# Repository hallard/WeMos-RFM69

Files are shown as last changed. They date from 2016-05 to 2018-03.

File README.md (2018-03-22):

ESP8266 WeMos Shield for HopeRF RFM69 and RFM12 Modules
=======================================================

This shield is used to hold HopeRF RF [module][4] Software with WeMos ESP8266 boards it has just few minimal features. 
- I2C Pullups placement
- Classic I2C 128x64 OLED connector
- Placement for RFM12B/RFM69CW/RFM69W/RFM69HW RF module
- Placement for choosing single Wire, SMA or u-FL Antenna type
- 2 x WS2812B Type LED for visual indication
- Atmel ATSHA204 for crypto
- Custom switch on GPIO2

You can find more information on WeMos on their [site][1], it's really well documented.
I now use WeMos boards instead of NodeMCU's one because they're just smaller, features remains the same, but I also suspect WeMos regulator far better quality than the one used on NodeMCU that are just fake of originals AMS117 3V3.

Boards heve been tested with RFM69HW and are working fine, no problem so far, just a silk error on V1.0, RFM module indication is reversed.
This mean that RFM69W/RFM69HW is for RFM12B/RFM69CW and vice-versa, please check with module pinout before soldering.
**This have been corrected on V1.0a+ release**

**I didn't tested with RFM12/RFM69CW module.** If someone tested and have it working (or not), please let me know.

Detailed Description
====================

Look at the schematics for more informations.

### Schematic  
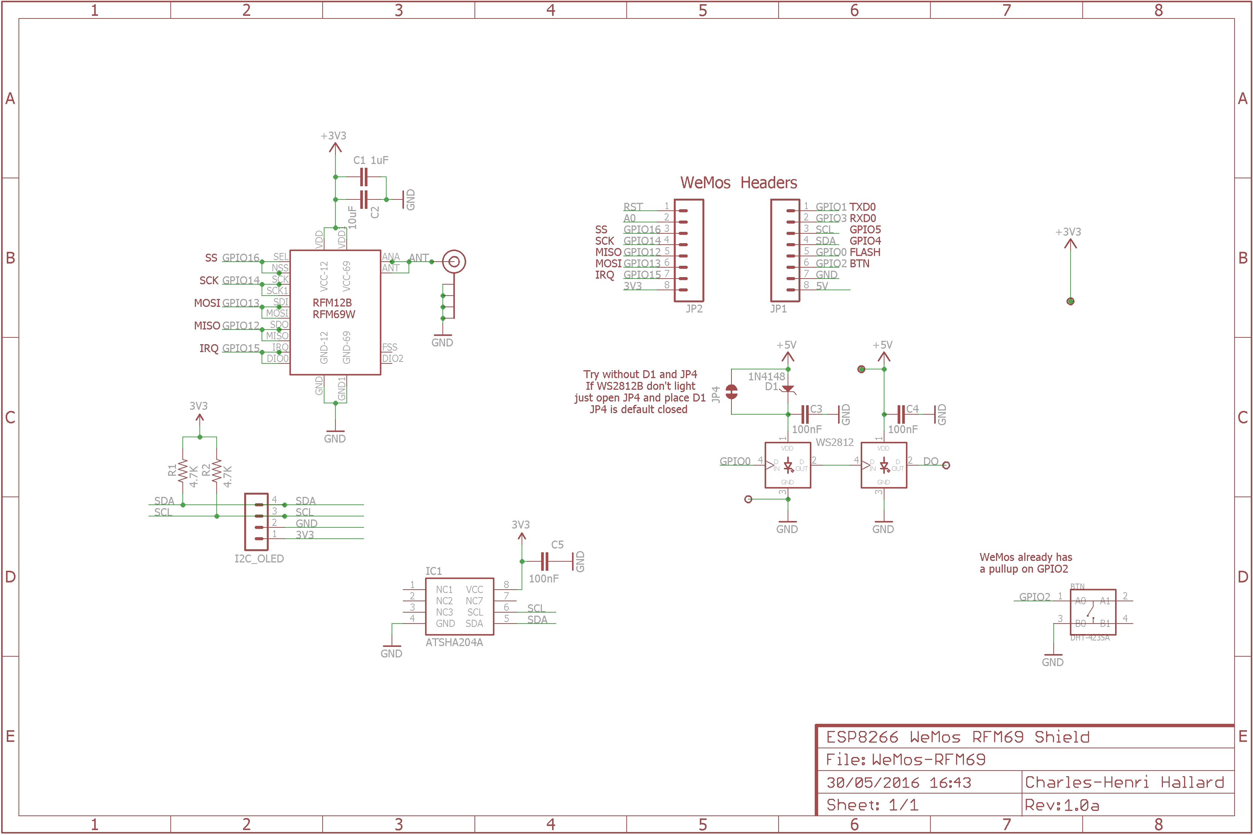
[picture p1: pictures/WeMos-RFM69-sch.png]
schematic
  

Diode D1 (1N4148) is for level voltage of WS2812B. Decreasing 1st led to VCC to 4.3V (see this [post][5]) but It should works out of the box (so without D1 and JP4 closed) without any problem. 
Depending on WS2812 type, if it does not work or flicker, open JP4 (cut wire) and put D1 in place.

### Boards  
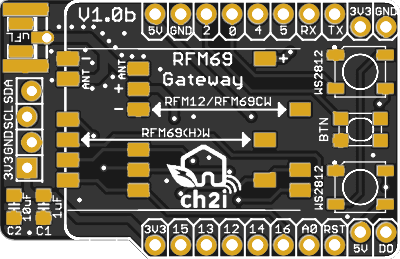
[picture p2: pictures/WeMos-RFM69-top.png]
Top
&nbsp;
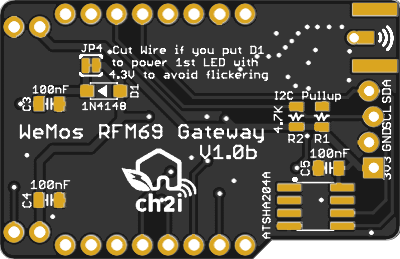
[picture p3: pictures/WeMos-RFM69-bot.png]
Bottom
 

You can order the PCB of this board at [PBCs.io][3], if you do so, PCBs.io give me little discount that allow me to buy some new created boards.

### Assembled boards

All assembled boards are working fine.

## License

   

This work is licensed under a [Creative Commons Attribution-NonCommercial 4.0 International License](http://creativecommons.org/licenses/by-nc/4.0/)    
If you want to do commercial stuff with this project, please contact [CH2i company](https://www.ch2i.eu/en#support) so we can organize an simple agreement.

## Misc
See news and other projects on my [blog][2] 
 
[1]: http://www.wemos.cc/wiki/doku.php?id=en:d1_mini
[2]: https://hallard.me
[3]: https://PCBs.io/share/8Vkkr 
[4]: http://www.hoperf.com/rf_transceiver/modules/
[5]: http://www.electrobob.com/ws2812-level-translator/

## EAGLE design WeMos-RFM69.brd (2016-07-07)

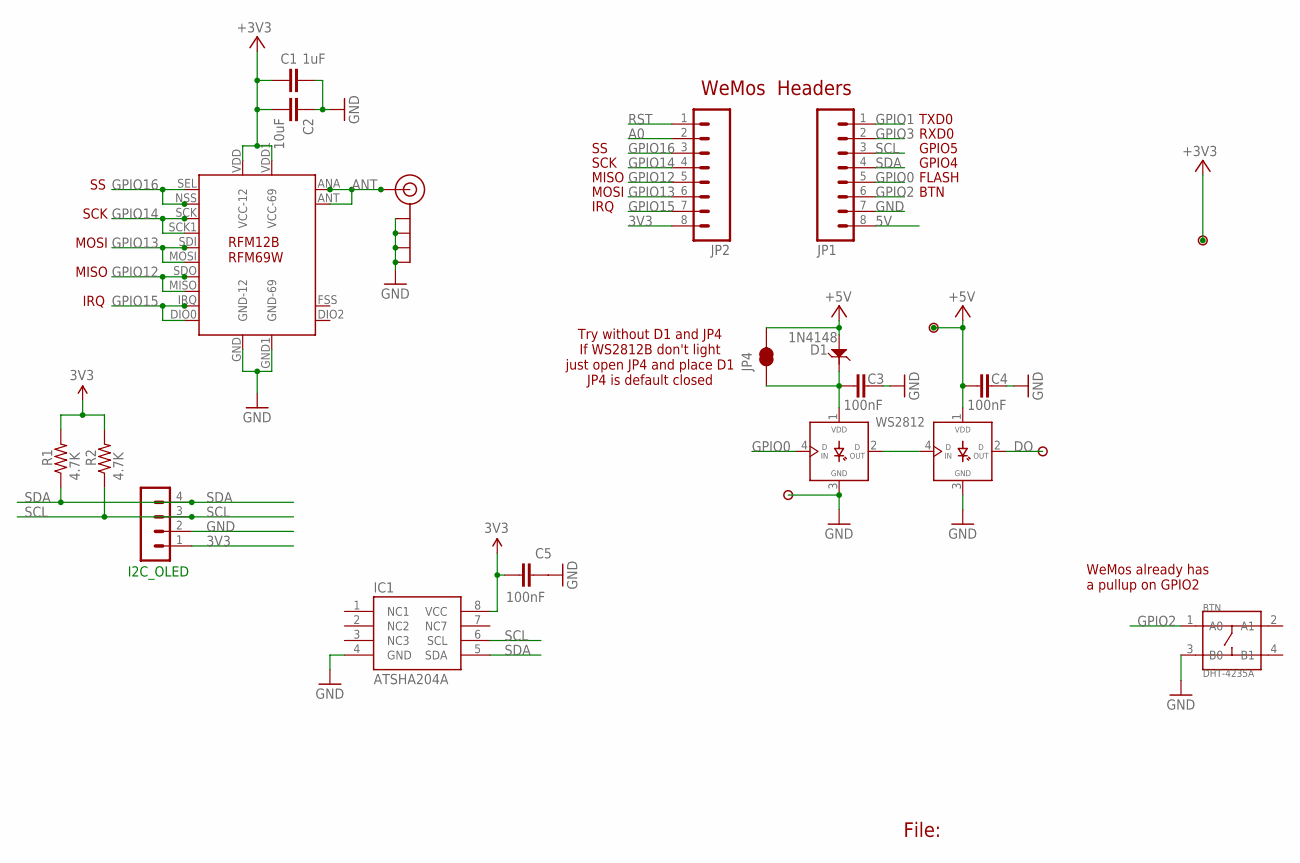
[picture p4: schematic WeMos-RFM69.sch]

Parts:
BTN: DHT-4235A; SW4-SMD-4.2X3.2X2.5MM
C1: 1uF; 0805-CAP-LARGEPADS
C2: 10uF; 0805-CAP-LARGEPADS
C3, C4, C5: 100nF; 0805-CAP
D1: 1N4148; SOD123-2.7X1.6
I2C_OLED: CON_HEADER_1X04'LOCK'; 1X04_LOCK
IC1: ATSHA204A; SOIC8
J$1: ANTENNATINY; SMA_UFL_PAD_TINY
JP1, JP2: M08NO_SILK_FEMALE_PTH; 1X08_NO_SILK
JP4: JUMPER-PAD-2-NC_BY_TRACE; PAD-JUMPER-2-NC_BY_TRACE_YES_SILK
P1, P2, P3, P4: PADNORMAL; PAD
R1, R2: 4.7K; 0805-RES
U$1: RFM-DUAL
WS1, WS2812: WS2812B

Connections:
3V3: C1.2, C2.2, C5.2, I2C_OLED.1, IC1.8 (VCC), JP2.8, P4.1, R1.2, R2.2, U$1.VDD (VCC-12), U$1.VDD1 (VCC-69)
5V: C4.1, D1.1, JP1.8, JP4.2, P1.1, WS1.1 (VDD)
A0: JP2.2
ANT: J$1.ANT1 (SIGNAL), J$1.ANT2 (SIGNAL), J$1.ANT3 (SIGNAL), U$1.ANA (ANT-12), U$1.ANT (ANT-69)
DO: P2.1, WS1.2 (DOUT)
GND: BTN.3 (B0), C1.1, C2.1, C3.2, C4.2, C5.1, I2C_OLED.2, IC1.4 (GND), J$1.GND1 (GND), J$1.GND2 (GND), J$1.GND3 (GND), J$1.GND4 (GND), JP1.7, P3.1, U$1.GND (GND-12), U$1.GND1 (GND-69), WS1.3 (GND), WS2812.3 (GND)
GPIO0: JP1.5, WS2812.4 (DIN)
GPIO1: JP1.1
GPIO2: BTN.1 (A0), JP1.6
GPIO3: JP1.2
GPIO12: JP2.5, U$1.MISO, U$1.SDO
GPIO13: JP2.6, U$1.MOSI, U$1.SDI
GPIO14: JP2.4, U$1.SCK, U$1.SCK1
GPIO15: JP2.7, U$1.DIO0, U$1.IRQ
GPIO16: JP2.3, U$1.NSS (SEL-12), U$1.SEL (SEL-69)
unnamed: WS1.4 (DIN), WS2812.2 (DOUT)
RST: JP2.1
SCL: I2C_OLED.3, IC1.6 (SCL), JP1.3, R2.1
SDA: I2C_OLED.4, IC1.5 (SDA), JP1.4, R1.1
VLED: C3.1, D1.2, JP4.1, WS2812.1 (VDD)

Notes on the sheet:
File:
FLASH
MISO
GPIO4
GPIO5
RXD0
TXD0
MOSI
SCK
IRQ
WeMos Headers
WeMos already has a pullup on GPIO2
BTN
Try without D1 and JP4 If WS2812B don't light just open JP4 and place D1 JP4 is default closed

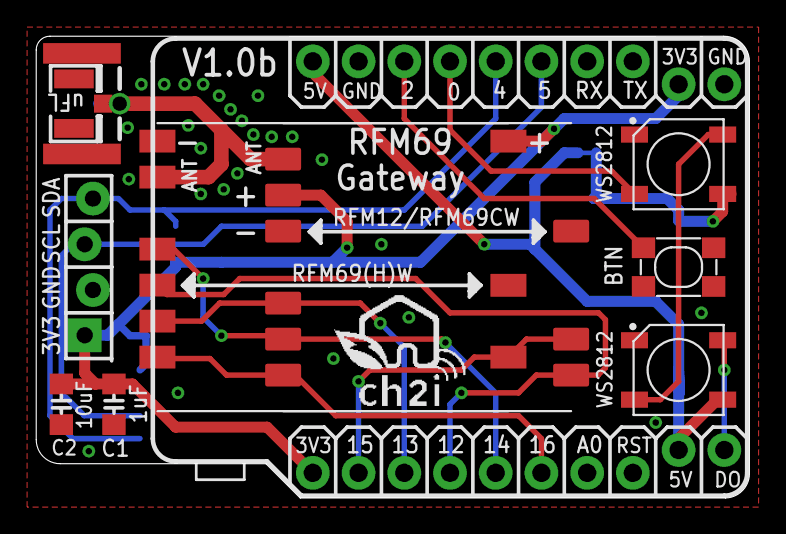
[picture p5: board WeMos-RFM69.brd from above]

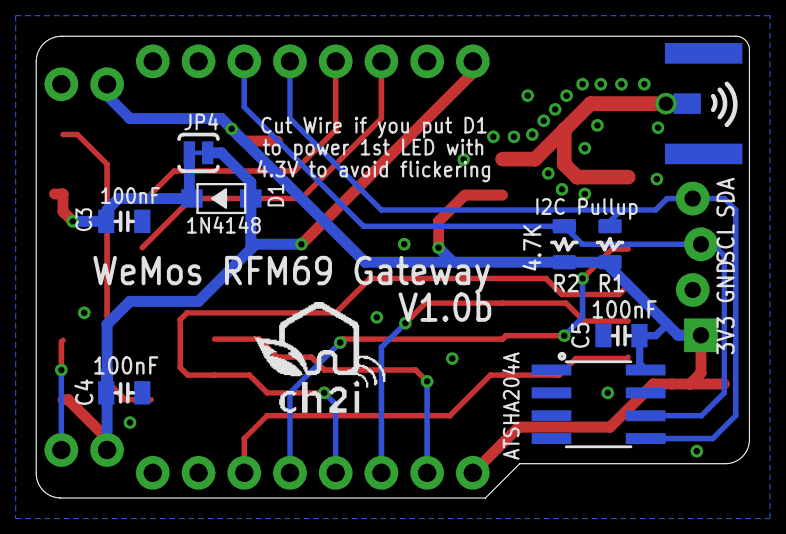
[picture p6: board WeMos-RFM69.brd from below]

Board: 2 copper layers, 39.6 x 25.7 mm, 24 parts (9 on the bottom side), 16 nets.

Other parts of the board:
U$2, U$4: LOGO_CH2I_75MM

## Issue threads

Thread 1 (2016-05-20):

testing finished?  Also, 1N4148 diode.

WhiteHare, 2016-05-20:
Your introductory post says, "Boards arrived from OSHPark, I did not fully tested them yet, I will update ASAP. Use at your own risks."

Have you had a chance to finish testing it yet, and if so, what were the results?

Also, specifically which SMD 1N4148 part do you recommend using?   Is it there entirely for polarity protection, such that simply shorting jumper J4 can be "good enough" without missing anything else?

BTW, I  like that you silkscreened the component values directly onto the board.  Also using the  two WS2812B's is a nice touch.

hallard, 2016-05-29:
@WhiteHare
thanks for the comment, I didn't had time to test them but I assembled one.
There is one error on the silkscreen for the module, they are reversed, IE
RFM69W and RFM69HW is for RFM12B and RFM69CW and vice-versa, please check with module pinout before soldering.
1N4148 diode is for level voltage of WS2812B decreasing 1st led to 4.3V (see this [post](http://www.electrobob.com/ws2812-level-translator/)) but It should works out of the box without any problem, depending on WS2812 type. In this case JP4 need to be closed.

hallard, 2016-05-30:
Tested with RFM69HW with 2 WS2812B RGBW LEDS, works fine, done a 1.0a release
- Correct RFM module silkscreen reversed
- New SMA-UFL connector

Closed 2016-05-30.

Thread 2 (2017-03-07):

Software examples

blebson, 2017-03-07:
I have created this board but am having issues when creating a program to use it. Do you have any software examples for use with this board?

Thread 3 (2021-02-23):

Are LEDs required for the shield to work?

phretor, 2021-02-23:

hallard, 2021-02-23:
Nop, Led can be driven by firmware if it's implemented, but leaving without then will not hurt anything, so the 2 I2C resistors if you don't have any 2IC devices.

phretor, 2021-02-23:
Wait, I don't understand. Are you saying I should *not* put any I2C resistors if I'm *not* using the LEDs?

Have you tested this shield with MySensors by any chance?

hallard, 2021-02-23:
No, sorry just saying:

- Led are optionals
- I2C pullup optionals if you're not using I2C devices

No relation between both

Closed 2021-02-23.

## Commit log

2016-05-30 File was misnamed
    [WeMos-RFM96.sch]
2016-05-30 Version 1.0a
    [WeMos-RFM69.brd, WeMos-RFM69.sch]
2016-07-07 Version 1.0b
    OLED Display connector has now lock pad
    Antenna signal with via
    ground plane set to 12min blocking to avoid short circuit with
    connectors
    [WeMos-RFM69.brd, WeMos-RFM69.sch]
2016-07-07 Picture from PCBs.io

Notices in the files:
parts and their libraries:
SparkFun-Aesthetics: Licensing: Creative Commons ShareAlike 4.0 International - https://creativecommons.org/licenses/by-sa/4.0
